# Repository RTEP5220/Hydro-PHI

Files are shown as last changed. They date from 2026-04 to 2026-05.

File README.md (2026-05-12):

# HydroPHI φ 💧

> **HydroPHI** — *Hydro* (Greek: liquid/water) · *φ* (phi: fluid dynamics flow rate symbol)
>
> **Genuinely real-time adaptive filling system — **








---

## Overview

**HydroPHI** *(φ — phi, fluid dynamics flow rate symbol)* is a fully autonomous adaptive filling system for Raspberry Pi 5. Place any container — bottle, mug, jug, shot glass — and the system detects it, profiles its geometry, and fills it precisely with zero operator input.

---

This GitHub repository showcases a real-time embedded systems project focused on developing 
an autonomous adaptive filling system. The system detects any container placed on the station, 
profiles its geometry using a time-of-flight laser sensor, and fills it precisely to the rim — 
with zero operator input, regardless of container size or shape.

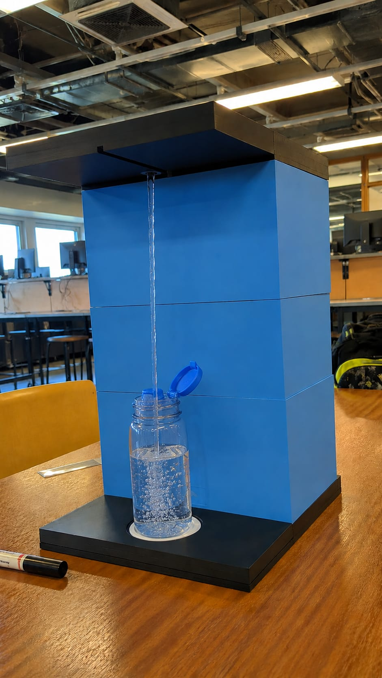
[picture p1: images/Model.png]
HydroPHI Model


---

## 📋 Agenda

- [Bill of Materials](#-bill-of-materials)
- [Getting Started](#-getting-started)
- [Tests](#-tests)
- [License](#-license)
- [Connect with Us](#-connect-with-us)

---

## 🧾 Bill of Materials

| Component | Qty |
|---|---|
| Raspberry Pi 5 | 1 |
| VL53L0X V2 ToF Laser Sensor module | 1 |
| HX711 Load Cell ADC breakout module | 1 |
| 5kg Load Cell (strain gauge, 4-wire) | 1 |
| IR Proximity Sensor (digital output) | 1 |
| Peristaltic Pump 12V DC | 1 |
| 5V Relay Module (single channel) | 1 |
| Silicone Tubing 6mm ID × 1m | 1 |
| Dispensing Nozzle 6mm | 1 |

---

## 📐 UML Sequence Diagram

This section outlines the planned UML sequence diagram for the HydroPHI automatic water filling system. The diagram shows the steps taken by the system after a user places a bottle on the platform.

The process begins when the user places a bottle, triggering the IR proximity sensor. The IR sensor signals the Pi controller, which boots the time-of-flight sensor and requests an initial depth measurement to compute the empty volume of the bottle. The Pi then opens the pump and enters a measurement loop: it continuously polls the ToF sensor for the current water level and compares it against the fill target.

When the water level reaches the target, the Pi closes the pump and signals the user that the bottle is filled.

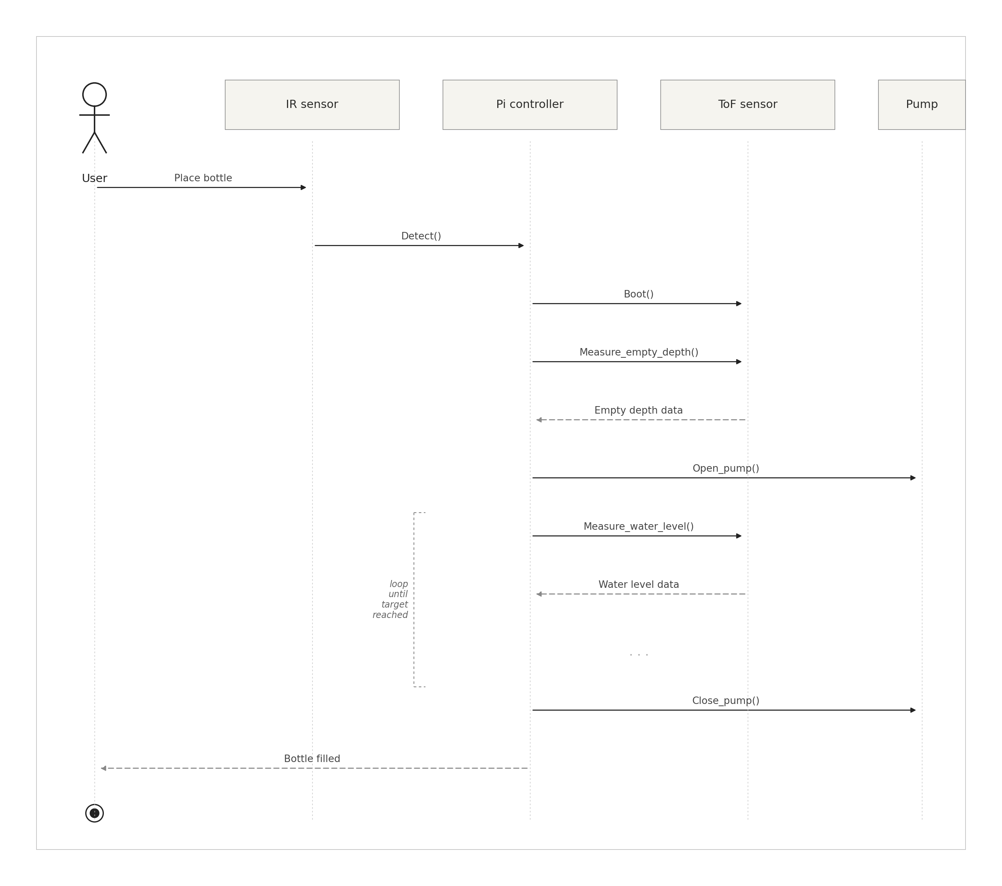
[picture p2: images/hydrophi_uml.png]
HydroPHI UML Sequence Diagram


---

## 🚀 Getting Started

### Prerequisites

```bash
sudo apt update && sudo apt upgrade -y
sudo apt install -y cmake g++ liblgpio-dev libi2c-dev i2c-tools
```

### Build

```bash
git clone https://github.com/RTEP5220/Hydro-PHI.git
cd Hydro-PHI
mkdir build && cd build
cmake ..
make -j4
```

### Run

```bash
# Recommended GPIO Config Coming Later.
sudo ./build/hphi
```
---

## 📄 License

[MIT License](LICENSE) — Copyright © 2026 HydroPHI

---

## 📱 Connect with Us

<p align="left">
<a href="https://www.instagram.com/hydro_phi" target="blank">instagramFollow our Instgram Page ! </a></br>

<a href="https://www.youtube.com/@hydrophi" target="blank">youtubeSubscribe to our Youtube Channel.</a>
</p>

<p align="left">
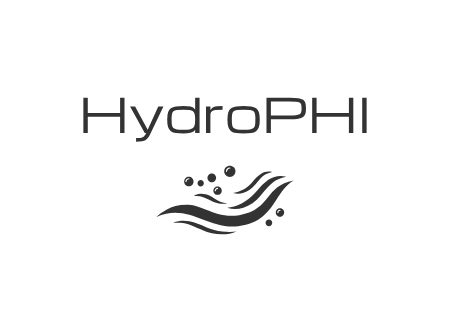
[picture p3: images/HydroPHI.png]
HYDRO-PHI Project
 </br>
</p>

<p align="center">
**HydroPHI φ**<br/>⚡ Genuinely Real-Time · 🔒 Lock-Free · Raspberry Pi 5 · C++17<br/>
HydroPHI φ · Team_3 Real-Time Embedded Programming . University of Glasgow
</p>

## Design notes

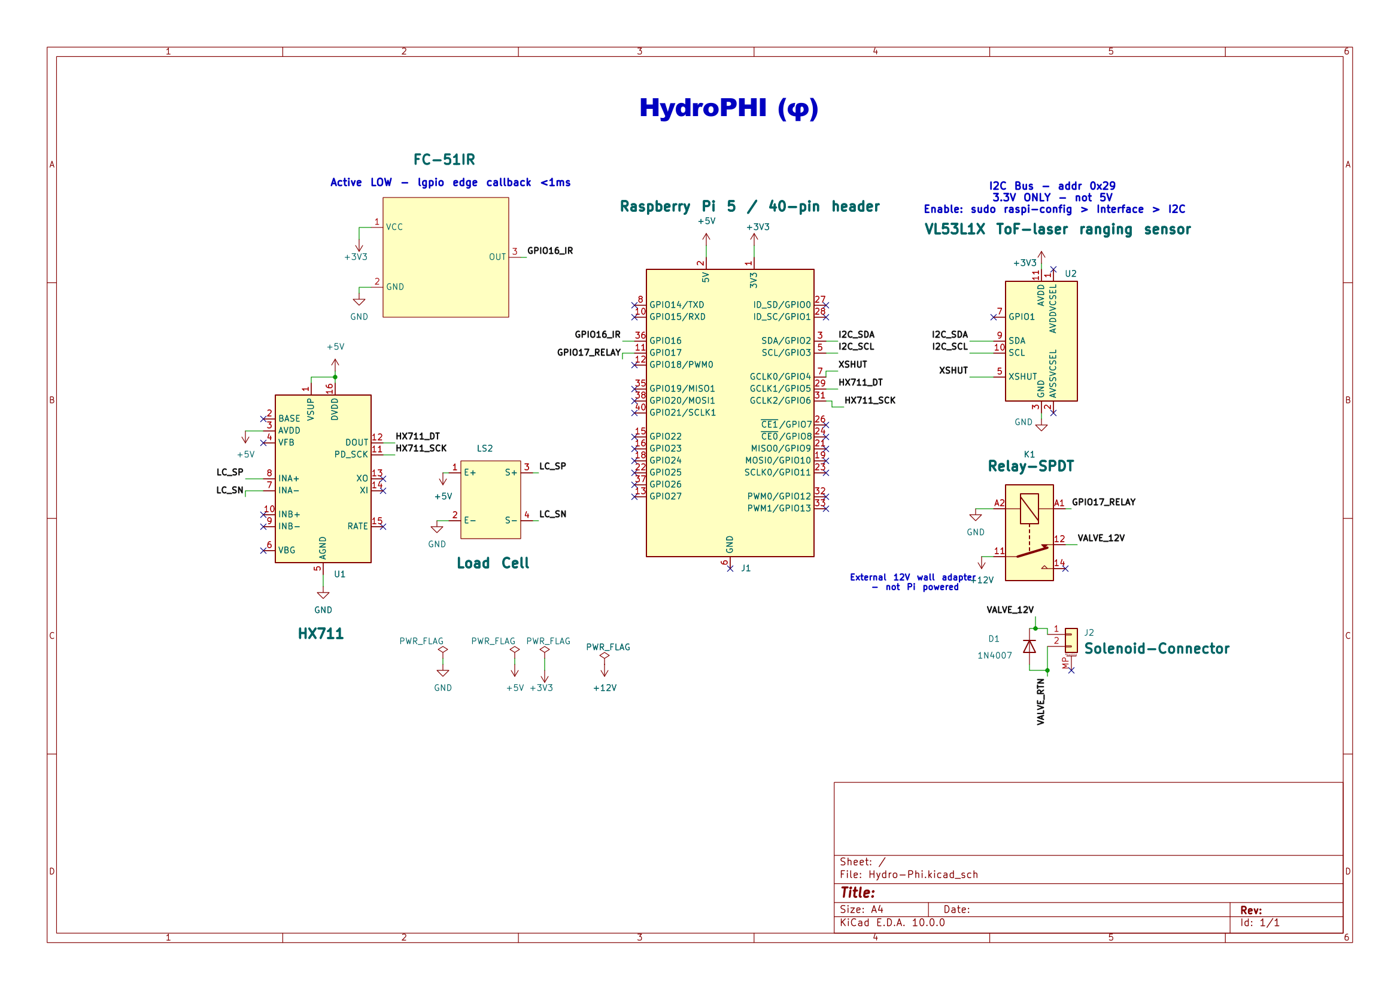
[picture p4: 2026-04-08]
Hardware/Hydro-Phi-1.png

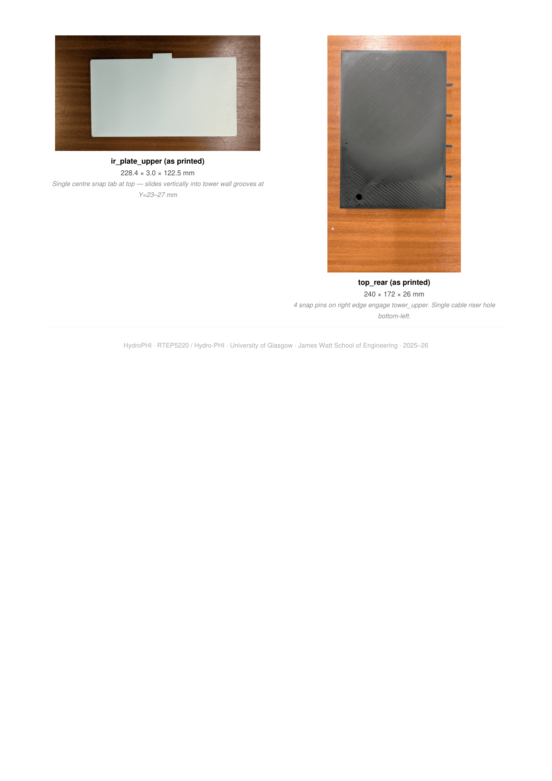
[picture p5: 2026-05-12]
3D Model/3D_models/3D_models-4.png

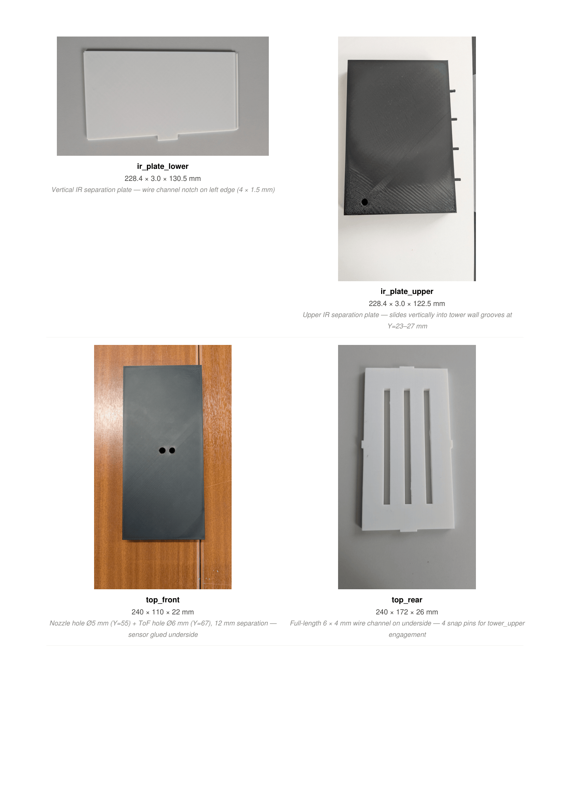
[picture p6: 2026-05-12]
3D Model/3D_models/3D_models-2.png

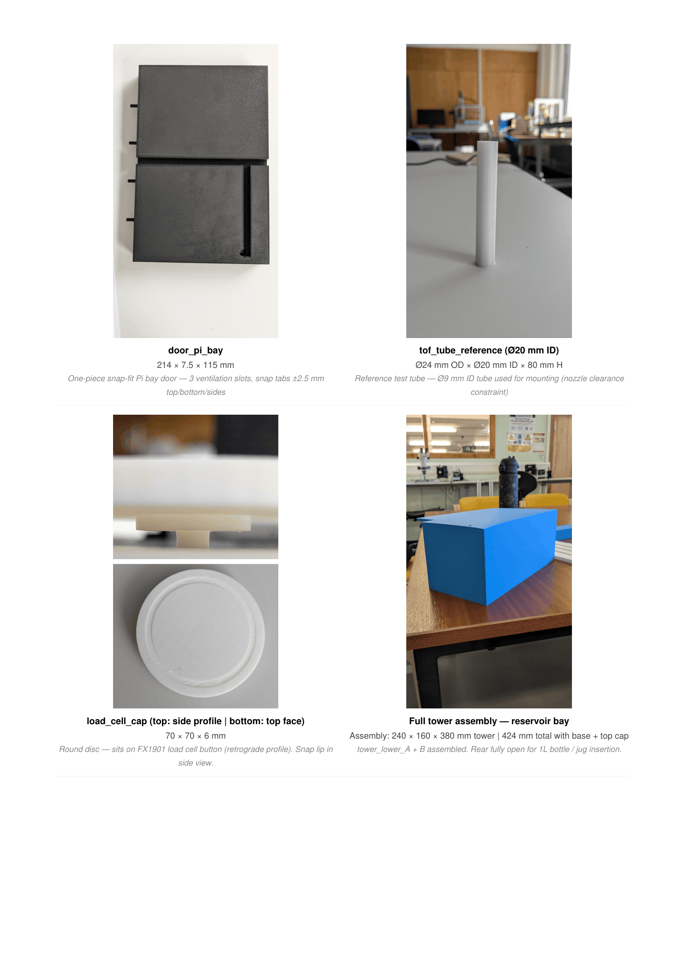
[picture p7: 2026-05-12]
3D Model/3D_models/3D_models-3.png

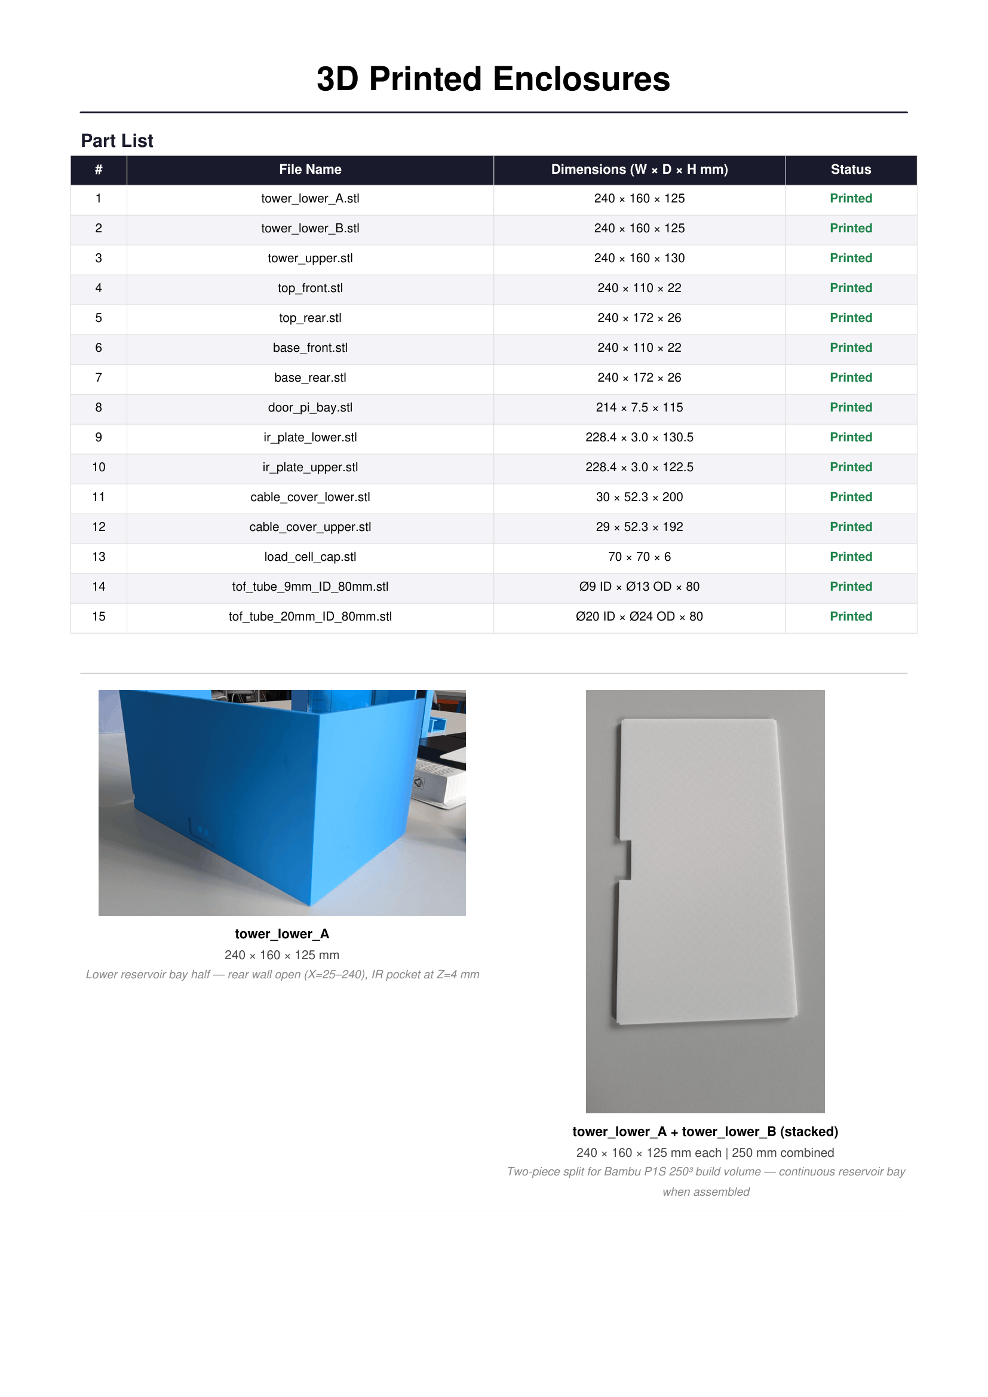
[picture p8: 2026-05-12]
3D Model/3D_models/3D_models-1.png

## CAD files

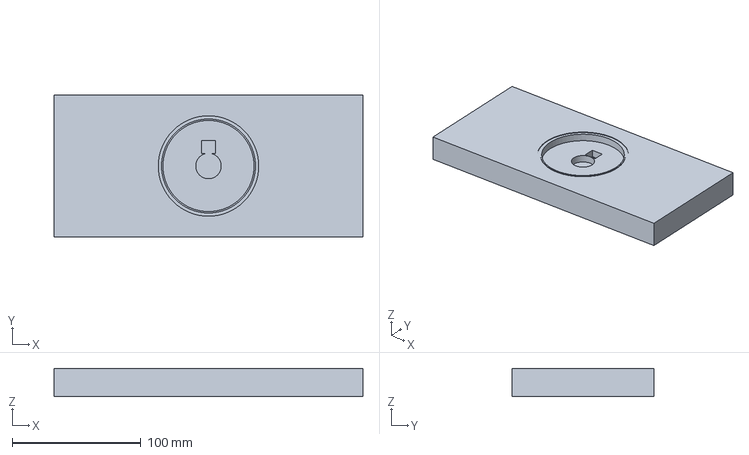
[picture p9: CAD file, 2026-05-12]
3D Model/gcode/Gcode/base_front.3mf
240.0 x 110.0 x 22.0 mm

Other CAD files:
3D Model/gcode/Gcode/IR plat_Lower.gcode.3mf
3D Model/gcode/Gcode/top_front.gcode.3mf
3D Model/gcode/Gcode/top_rear.gcode.3mf
3D Model/gcode/Gcode/tower_upper.gcode.3mf
3D Model/gcode/Gcode/Pi_door.gcode.3mf
3D Model/gcode/Gcode/Cable_cover_lower.gcode.3mf
3D Model/gcode/Gcode/tof_tube_20mm_ID_80mm.gcode.3mf
3D Model/gcode/Gcode/Cable_cover_upper.gcode.3mf
3D Model/gcode/Gcode/tower_lower_A.gcode.3mf
3D Model/gcode/Gcode/IR plat_Upper.gcode.3mf
3D Model/gcode/Gcode/Tower_lowerB.gcode.3mf
3D Model/gcode/Gcode/tof_tube_9mm_ID_80mm.gcode.3mf
3D Model/gcode/Gcode/load_cell_cap_new.gcode.3mf
3D Model/gcode/Gcode/base_rear.gcode.3mf

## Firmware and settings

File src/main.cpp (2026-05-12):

#include <iostream> 
#include <thread> 
#include <chrono>
#include <csignal>
#include <lgpio.h>
#include<atomic>
#include "IRSensor.hpp"
#include "Relay.hpp"
#include "ToFSensor.hpp"
#include "LoadCell.hpp"



// static bool running = true; - Change to atomic for thread safety.
static std::atomic<bool> running{true};

static std::atomic<bool> container_present{false};
// static bool container_present = false;
void sigHandler(int) { running = false; }

//Defining the State Machine for the Filling Process.
enum class State { IDLE, SCANNING, FILLING, DONE };



int main() {


std::cout << "HydroPHI starting...\n";

/////////////////////// ToF Calibration Block /////////////////////////
///// Open ToF - Ensure it is Ready.
ToFSensor tof(1, 0x29);
if (!tof.open()) {
    std::cerr << "ToF failed\n";
    return 1;
}
std::cout << "ToF ready\n";

// Take baseline - Calibration Process//
float base = tof.baseline(5);
std::cout << "Baseline = " << base << " cm\n";
if (base < 10.0f){
    std::cerr << "Baseline is too small - Ensure the Platform is Free.\n";
    return 1;
}
//////////////////////////END of ToF Calibration Block //////////////////////.

// Open GPIO chip 0 (the first one) and get a handle for GPIO access.
    int gpio_handle = lgGpiochipOpen(0);
    if (gpio_handle < 0) {
        std::cerr << "Failed to open GPIO chip\n";
        return 1;
    }
    // Successfully opened GPIO chip, now we can initialize our IR sensor and relay.
    std::cout << "GPIO chip opened successfully\n";

////////////////////////////INITIALIZING SENSORS - ACTUATORS//////////////////////////////////////////

    // Initialize the relay on GPIO pin 22.
    Relay relay(gpio_handle, 22);
    if (!relay.init()) {
        std::cerr << "Pump initialization failed\n";
        lgGpiochipClose(gpio_handle);
        return 1;
    }
    std::cout << "Pump Ready\n";
//Initializing the Load Cell on GPIO pins 20 (DOUT) and 21 (SCK).
LoadCell lc(5, 6, gpio_handle);  // DOUT=GPIO5, SCK=GPIO6
if (!lc.init()) {
    std::cerr << "[LoadCell] Initialization Failed\n";
    lgGpiochipClose(gpio_handle);
    return 1;
}
std::cout << "[LoadCell] Ready\n";

    // Initialize the IR sensor on GPIO pin 16, active low configuration.
    IRSensor ir(16, gpio_handle, false);
    if (!ir.init([](bool present) {
      container_present.store(present, std::memory_order_release); 
        if (present) {               
            std::cout << "Container detected\n";             
        } else {
            std::cout << "Container removed \n";
        }
    })) {
        std::cerr << "IR init failed\n";
        lgGpiochipClose(gpio_handle);
        return 1;
    }
    std::cout << "IR sensor ready\n";

    // Set up signal handler for shutdown on Ctrl+C.
    signal(SIGINT, sigHandler);

    // Defining Initial State, rim and target fill.
    // float to cm conversion is handled inside the ToF class.
    State state = State::IDLE;
    float rim    = 0.0f;
    float target = 0.0f;

/////////// Process Preparation  /////////////////////////
    
/////////1. Actuator Safety //////////////////////////////// 

    relay.off(); // Ensure the pump is off at startup. - Safety First.

///////// 2. Prepare the LoadCell /////////
lc.tare(); 
lc.startThread();


//////////////////////3. Prepare the Thread for System inspection 
    tof.startThread(); // Starting the ToF Thread.

  
 
/////////////////////4. System Ready ////////////////////////////////
    std::cout << "Place a container...\n";
       
///////////////// Start Filling Process using 4-States ///////////////////////

///// According to State, each Case is handled ////////////////////////////// 

while (running) {
    
        // Sate IDLE //  
        switch(state) {
            case State::IDLE:
            relay.off();
            if (container_present.load(std::memory_order_acquire)) {
            std::cout << "IDLE: Container detected - Scanning Process ... \n";
            state = State::SCANNING;
            }else {
            relay.off();
            std::this_thread::sleep_for(std::chrono::milliseconds(50));
            }break;

            // In the SCANNING state, 
            // we take a baseline measurement to find the rim level of the container.
            case State::SCANNING: {
            if (!container_present.load(std::memory_order_acquire)) {
            
            std::cout << "SCANNING: Container removed - Back to IDLE\n";
            state = State::IDLE;
            break;
            }
            std::cout << "SCANNING: Measuring Container Rim...\n";
            tof.stopThread();
            // Take 3 Samples 3 Samples to ensure stable reading. 
            float r = tof.baseline(3, container_present); //r is the media distance from ToF
            // to the container rim.
            
            tof.startThread();

            if (r < 0 || !container_present.load(std::memory_order_acquire)) {
            std::cout << "SCANNING: Aborted - Container Removed\n";
            state = State::IDLE;
            break;
            }
            // The drop is the distance needed to fill the container.
            // Drop is equal to the difference between the baseline (platform) and the rim level.
            float drop = base - r;
            std::cout << "SCANNING: Rim=" << r << "cm  drop=" << drop << "cm\n";

            if (drop < 2.0f) {
            std::cout << "SCANNING: Height of Container too Small — Retrying\n";
            std::this_thread::sleep_for(std::chrono::milliseconds(50));
            break;
             }
        // Storing Rim and Filling Target Calculations (in Percentage).
        rim    = r;
        target = rim +(drop * 0.90f); // Target (Target Filling) = 90% of Container. - Leaving 10% Safety Margin.
        std::cout << "SCANNING: Filling Target = " << target << " cm\n";
        relay.on();
        std::cout << "SCANNING: Pump ON - Filling Process ... \n";
        state = State::FILLING;
        break;
        }
        // In the FILLING state, 
        // we continuously monitor the distance until we reach the target level 
        // Or the container is removed.          
            case State::FILLING: {
            if (!container_present.load(std::memory_order_acquire)) {
            relay.off();
            std::cout <<"FILLING: Container Removed — Pump OFF\n";
            state = State::IDLE;
            break;
            }

            float d = tof.getLatest(); // Get the Latest distance -Sync- Reading from ToF.
          
        if (!container_present.load(std::memory_order_acquire)) {
        relay.off();
        std::cout << "FILLING: Container removed — pump OFF\n";
        state = State::IDLE;
        break;
            }
                if (d < 0) {
                std::this_thread::sleep_for(std::chrono::milliseconds(100));
                break;
               }
             std::cout << "Filling " << d << "cm  Target=" << target << "cm\n";
             
             if (d > 0 && d < base && d <= target) {
                relay.off();
                std::cout << "FILLING: Fill Complete - Pump OFF\n";
                state = State::DONE;
                break;
                }

        if (!container_present.load(std::memory_order_acquire)) {
        relay.off();
        std::cout << "FILLING: Container removed — pump OFF\n";
        state = State::IDLE;
        break;
    }

                std::this_thread::sleep_for(std::chrono::milliseconds(50));
                break;
                }

              // DONE State
              // Container is Filled and Successfully Removed 
              // System waits for the next container.

                case State::DONE:
                relay.off();
                if (!container_present.load(std::memory_order_acquire)) {
                std::cout << "DONE: Container Removed - Ready for Next ... \n\n";
                state = State::IDLE;
                } else {
                std::this_thread::sleep_for(std::chrono::milliseconds(50));
                }
                break;
                // default:
                //  state = State::IDLE;
        }
    }
    
    // Clean up: turn off the relay and close the GPIO handle before exiting.
    tof.stopThread(); // Closing the ToF Thread.
    lc.stopThread(); // Stop LoadCell Thread.
    relay.off(); // Turn the Pump off 
    lgGpiochipClose(gpio_handle); // Releasing GPIO
    std::cout << "Done\n";
    return 0;
}


// ______________________________

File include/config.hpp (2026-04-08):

#pragma once
#include <string>

// ─────────────────────────────────────────────────────────────────────────────
// Configuration structs — loaded from settings.cfg at startup

// ─────────────────────────────────────────────────────────────────────────────

struct TofConfig {
    int    i2c_bus            = 1;
    int    i2c_address        = 0x29;
    float  baseline_cm        = 30.0f;
    float  rim_detect_delta   = 3.0f;
    float  safety_margin_cm   = 1.5f;
    int    poll_interval_ms   = 100;
};

struct LoadCellConfig {
    int    data_pin            = 5;
    int    clock_pin           = 6;
    float  calibration_factor  = 420.0f;
    int    poll_interval_ms    = 80;
    float  weight_delta_g      = 1.0f;
    int    stable_cycles       = 6;
    float  present_threshold_g = 10.0f;
};

struct IRConfig {
    int    gpio_pin   = 16;
    bool   active_low = true;
};

struct ActuatorConfig {
    // Peristaltic pump.
    int    pump_pin = 22;
 
};

struct ControllerConfig {
    int    fill_timeout_s = 60;
    int    idle_scan_ms   = 50;
};

struct ThreadConfig {
    int    sensor_priority     = 80;
    int    safety_priority     = 90;
    int    controller_priority = 70;
    int    logger_priority     = 0;
};

struct LogConfig {
    bool        enable     = true;
    std::string log_file   = "/var/log/HydroPHI/fill_log.csv"; // Log file Container Volume / TimeStamp
    std::string log_level  = "INFO";
    int         queue_size = 256;
};

struct AppConfig {
    TofConfig        tof;
    LoadCellConfig   load_cell;
    IRConfig         ir;
    ActuatorConfig   actuator;
    ControllerConfig controller;
    ThreadConfig     threads;
    LogConfig        logging;
};

class Config {
public:
    static AppConfig load(const std::string& path);
};

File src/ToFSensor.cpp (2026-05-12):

#include "ToFSensor.hpp"
#include <iostream>
#include <string>

// Constructor to initialize the ToF sensor 
// with the specified I2C bus and address.
ToFSensor::ToFSensor(int bus, int address)
    : bus_(bus)
    , address_(address)
    , fd_(-1)
    , sv_(0)
{}

// Destructor - just close the file descriptor
// Never write to sensor here - puts it to sleep
ToFSensor::~ToFSensor() {
    stopThread();
    if (fd_ >= 0) close(fd_);
}

// Write one byte to a register
void ToFSensor::wr8(uint8_t reg, uint8_t val) {
    uint8_t buf[2] = {reg, val};
    ::write(fd_, buf, 2);
}

// Read one byte from a register
uint8_t ToFSensor::rd8(uint8_t reg) {
    ::write(fd_, &reg, 1);
    uint8_t val = 0;
    ::read(fd_, &val, 1);
    return val;
}

// Read two bytes from a register 
// combine them into a 16-bit value.
uint16_t ToFSensor::rd16(uint8_t reg) {
    ::write(fd_, &reg, 1);
    uint8_t buf[2] = {};
    ::read(fd_, buf, 2);
    return static_cast<uint16_t>((buf[0] << 8) | buf[1]);
}


//////////////Sensor Initialization.

 bool ToFSensor::open() {
    // Open the I2C bus
    std::string dev = "/dev/i2c-" + std::to_string(bus_);
    fd_ = ::open(dev.c_str(), O_RDWR);
    if (fd_ < 0) {
        std::cerr << "[ToF] Cannot open " << dev << "\n";
        return false;
    }

    // Set the I2C slave address
    if (ioctl(fd_, I2C_SLAVE, address_) < 0) {
        std::cerr << "[ToF] Cannot set slave address\n";
        return false;
    }

    // Wake sensor from any previous sleep state
    uint8_t wake[2] = {0x80, 0x00};
    ::write(fd_, wake, 2);
    usleep(10000);  // 10ms settle

    // Check model ID
    // VL53L0X Returns 0xEE
    uint8_t id = rd8(0xC0);
    if (id != 0xEE) {
        std::cerr << "[ToF] Wrong model ID: 0x" << std::hex << (int)id << "\n";
        return false;
    }
    std::cout << "[ToF] VL53L0X detected  rev=0x"
              << std::hex << (int)rd8(0xC2) << std::dec << "\n";

    // Run initialisation sequence
    if (!init()) {
        std::cerr << "[ToF] Init sequence failed\n";
        return false;
    }

    std::cout << "[ToF] Ready on " << dev << "\n";
    return true;
}

////

bool ToFSensor::init() {
    // Store stop variable - needed for single-shot ranging later
    wr8(0x88, 0x00);
    wr8(0x80, 0x01); wr8(0xFF, 0x01); wr8(0x00, 0x00);
    sv_ = rd8(0x91);
    wr8(0x00, 0x01); wr8(0xFF, 0x00); wr8(0x80, 0x00);

    // ST required tuning values 
    static const uint8_t tuning[][2] = {
        {0xFF,0x01},{0x00,0x00},{0xFF,0x00},{0x09,0x00},
        {0x10,0x00},{0x11,0x00},{0x24,0x01},{0x25,0xFF},
        {0x75,0x00},{0xFF,0x01},{0x4E,0x2C},{0x48,0x00},
        {0x30,0x20},{0xFF,0x00},{0x30,0x09},{0x54,0x00},
        {0x31,0x04},{0x32,0x03},{0x40,0x83},{0x46,0x25},
        {0x60,0x00},{0x27,0x00},{0x50,0x06},{0x51,0x00},
        {0x52,0x96},{0x56,0x08},{0x57,0x30},{0x61,0x00},
        {0x62,0x00},{0x64,0x00},{0x65,0x00},{0x66,0xA0},
        {0xFF,0x01},{0x22,0x32},{0x47,0x14},{0x49,0xFF},
        {0x4A,0x00},{0xFF,0x00},{0x7A,0x0A},{0x7B,0x00},
        {0x78,0x21},{0xFF,0x01},{0x23,0x34},{0x42,0x00},
        {0x44,0xFF},{0x45,0x26},{0x46,0x05},{0x40,0x40},
        {0x0E,0x06},{0x20,0x1A},{0x43,0x40},{0xFF,0x00},
        {0x34,0x03},{0x35,0x44},{0xFF,0x01},{0x31,0x04},
        {0x4B,0x09},{0x4C,0x05},{0x4D,0x04},{0xFF,0x00},
        {0x44,0x00},{0x45,0x20},{0x47,0x08},{0x48,0x28},
        {0x67,0x00},{0x70,0x04},{0x71,0x01},{0x72,0xFE},
        {0x76,0x00},{0x77,0x00},{0xFF,0x01},{0x0D,0x01},
        {0xFF,0x00},{0x80,0x01},{0x01,0xF8},
        {0xFF,0x01},{0x8E,0x01},{0x00,0x01},
        {0xFF,0x00},{0x80,0x00}
    };
    for (auto& p : tuning) wr8(p[0], p[1]);

    // Configure interrupt
    wr8(0x0A, 0x04);
    wr8(0x84, rd8(0x84) & ~0x10);
    wr8(0x0B, 0x01);
    wr8(0x01, 0xE8);

    // VHV calibration
    wr8(0x01, 0x01);
    wr8(0x00, 0x01 | 0x40);
    usleep(10000);
    for (int t = 0; t < 2000 && (rd8(0x13) & 7) == 0; t++) usleep(1000);
    if ((rd8(0x13) & 7) == 0) {
        std::cerr << "[ToF] VHV calibration timeout\n";
        return false;
    }
    wr8(0x0B, 0x01); wr8(0x00, 0x00);
    usleep(10000);

    // Phase calibration
    wr8(0x01, 0x02);
    wr8(0x00, 0x01);
    usleep(10000);
    for (int t = 0; t < 2000 && (rd8(0x13) & 7) == 0; t++) usleep(1000);
    if ((rd8(0x13) & 7) == 0) {
        std::cerr << "[ToF] Phase calibration timeout\n";
        return false;
    }
    wr8(0x0B, 0x01); wr8(0x00, 0x00);
    usleep(10000);

    wr8(0x01, 0xE8);
    return true;
}


/// ToF measurement///

// Single blocking measurement 
// Returns distance in cm, -1 on error
float ToFSensor::measure() {
    std::lock_guard<std::mutex> lock(mtx_); // Ensure thread safety if called from multiple threads.
    // Trigger single-shot ranging
    wr8(0x80, 0x01); wr8(0xFF, 0x01); wr8(0x00, 0x00);
    wr8(0x91, sv_);
    wr8(0x00, 0x01); wr8(0xFF, 0x00); wr8(0x80, 0x00);
    wr8(0x00, 0x01);

    // Wait for sensor to accept.
    for (int t = 0; t < 200 && (rd8(0x00) & 1); t++) usleep(1000);

    // Wait for result ready
    for (int t = 0; t < 300 && (rd8(0x13) & 7) == 0; t++) usleep(1000);

    // Read raw range result
    uint16_t raw = rd16(0x1E);

    // Clear interrupt
    wr8(0x0B, 0x01);

    // Validate result
    if (raw >= 8190) return -1.0f;
    float cm = raw / 10.0f;
    if (cm < 1.0f || cm > 120.0f) return -1.0f;
    return cm;
}

// Take N measurements and return the median
// Median is more reliable than average.
float ToFSensor::baseline(int n) {
    std::vector<float> readings;
    for (int i = 0; i < n; i++) {
        float d = measure();
        if (d > 0) readings.push_back(d);
        usleep(260000);  // 260ms between measurements
    }
    if (readings.empty()) return -1.0f;
    std::sort(readings.begin(), readings.end());
    return readings[readings.size() / 2];
}

float ToFSensor::baseline(int n, const std::atomic<bool>& run_flag) {
    std::vector<float> readings;
    for (int i = 0; i < n; i++) {
        if (!run_flag) return -1.0f;
        float d = measure();
        if (d > 0) readings.push_back(d);
        usleep(260000);
    }
    if (readings.empty()) return -1.0f;
    std::sort(readings.begin(), readings.end());
    return readings[readings.size() / 2];
}

// Start a background thread that continuously measures distance and updates the value.
void ToFSensor::startThread() { 
    thread_running_ = true;
    thread_ = std::thread([this]() {
        while (thread_running_) {
            float d = measure();  // blocks its own thread
            latest_distance_.store(d, std::memory_order_release);
        }
    });
}
// Stop the background thread and wait for it to finish.
void ToFSensor::stopThread() {
    thread_running_ = false;
    if (thread_.joinable()) thread_.join();
}

// Get the latest distance measurement from the background thread.
float ToFSensor::getLatest() const {
    return latest_distance_.load(std::memory_order_acquire);
}

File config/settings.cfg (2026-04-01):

[tof_sensor]
i2c_bus          = 1           # /dev/i2c-1 on Raspberry Pi 5
i2c_address      = 0x29        # VL53L1X default I2C address
baseline_cm      = 30.0        # Auto-calibrated at startup (no container present)
rim_detect_delta = 3.0         # Min cm drop from baseline to confirm container rim
safety_margin_cm = 1.5         # Gap left below rim as fill stop point
poll_interval_ms = 100         # ToF sensor thread cadence (ms)

[load_cell]
data_pin            = 5        # HX711 DOUT — lgpio GPIO pin
clock_pin           = 6        # HX711 PD_SCK — lgpio GPIO pin
calibration_factor  = 420.0    # ADC units per gram — calibrate on first run
poll_interval_ms    = 80       # Load cell thread cadence (ms)
weight_delta_g      = 1.0      # Max weight change per cycle to count as stable
stable_cycles       = 6        # Stable cycles required to confirm full
present_threshold_g = 10.0     # Minimum weight (g) to confirm container on scale

[ir_proximity]
gpio_pin  = 16                 # Digital IR proximity sensor GPIO pin
active_low = true              # LOW = container present (most IR modules)

[actuator]
# Peristaltic pump only — solenoid removed. Tube self-seals on motor stop.
pump_pin  = 22                 # Relay GPIO for peristaltic pump motor
# GPIO 23 is free — available for nozzle servo, drip tray, etc.

[controller]
fill_timeout_s = 60            # Abort fill if it exceeds this duration (seconds)
idle_scan_ms   = 50            # Controller loop period in ms (all states)

[threads]
sensor_priority     = 80       # ToF + LoadCell sensor threads
safety_priority     = 90       # IR lgpio alert thread (managed by lgpio)
controller_priority = 70       # Controller state machine thread
# worker runs at controller_priority - 10 = 60 (set programmatically)
logger_priority     = 0        # Logger: SCHED_OTHER (non-RT by design)

[logging]
enable     = true
log_file   = /var/log/Hydro-PHI/fill_log.csv
log_level  = INFO              # DEBUG, INFO, WARN, ERROR
queue_size = 256               # Async log queue depth (entries)

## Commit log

2026-03-29 Update Configurating - Settings
    [settings.cfg]
2026-03-29 Update Settings
    [settings.cfg]
2026-04-01 hardware: add HydroPHI schematic PDF
2026-04-06 Add Sensors Config - LoadCell Sensor Header
2026-04-06 Add Sensors Config- Modify LoadCell Header
2026-04-06 Initial Classes - IR Prox - Actuator (Pump)
2026-04-08 Add hardware pin connection schematic
2026-04-09 Add Actuator-Pump Control
2026-04-13 Add IR-TEST and IR-REL-PUMP files
2026-04-16 Move IR files into Hardware/IR-Sensors folder
2026-04-16 Move IR-REL-PUMP into Hardware/IR-Sensors folder
2026-05-12 Add gcode folder inside 3D Model
    [Cable_cover_lower.gcode.3mf, Cable_cover_upper.gcode.3mf, IR plat_Lower.gcode.3mf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]
